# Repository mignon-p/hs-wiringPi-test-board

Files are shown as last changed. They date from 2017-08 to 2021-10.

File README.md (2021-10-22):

This is a simple add-on board for [Raspberry Pi][1].  It is meant for
testing the [Haskell binding for wiringPi][2].  It connects to the
Raspberry Pi via a 40-pin ribbon cable, and has the following
features:

* [wiringPi pins][3] 0-7 are connected to yellow LEDs

* wiringPi pins 26 and 23 are connected to red LEDs

* wiringPi pins 21 and 22 are connected to each other (via a resistor
  to prevent short circuits) to allow for automated testing (i. e. an
  output pin sending to an input pin)

* wiringPi pin 25 is connected to a momentary pushbutton which pulls
  it to ground via a resistor (so pin should be configured with an
  internal pullup)

The LEDs are driven [with transistors][4] from the 5V supply, to avoid
overloading the 3.3V supply.

This circuit board was designed with [KiCad][5], and was designed to
be fabricated with [OSH Park][6].

* [View schematic](schematic.pdf)
* [View PCB layout][9]
* [Order PCB from Osh Park][10] ($27.40 for three copies of the board,
  and free shipping)

See `digi-key.csv` for Bill of Materials with [Digi-Key][7] part
numbers.  With the 33 ohm resistors, the LEDs are really bright, so
you might want to substitute 68 ohm resistors instead.

This repository is licensed under the
[Creative Commons Attribution-ShareAlike 4.0 International license][8].

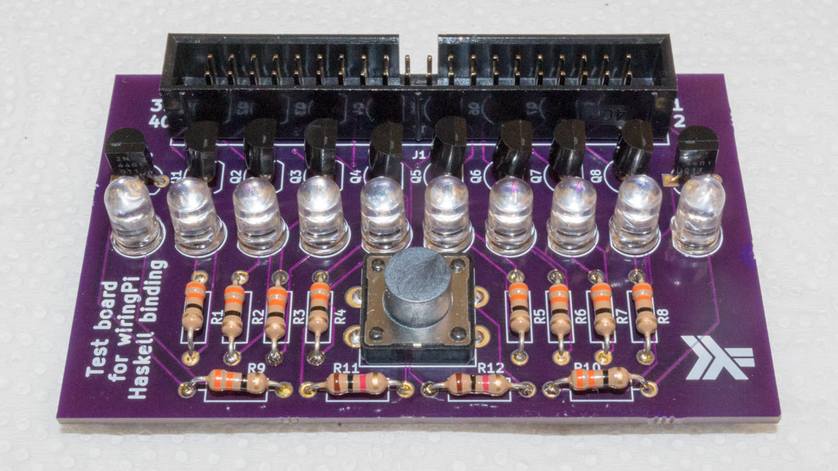
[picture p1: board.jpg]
photo of board


[1]: https://www.raspberrypi.org/
[2]: https://hackage.haskell.org/package/wiringPi
[3]: https://pinout.xyz/pinout/wiringpi
[4]: https://electronics.stackexchange.com/questions/60865/how-to-drive-a-20ma-led-from-a-4ma-max-gpio-pin#60868
[5]: http://kicad.org/
[6]: https://oshpark.com/
[7]: https://www.digikey.com/
[8]: https://creativecommons.org/licenses/by-sa/4.0/
[9]: https://eyrie.io/board/922367d680304403abe881f246e2a430
[10]: https://oshpark.com/shared_projects/bw71UDHZ

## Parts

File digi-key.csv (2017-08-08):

# | Quantity | Part Number | Manufacturer Part Number | Description | Customer Reference | Backorder | Unit Price | Extended Price
1 | 10 | 2N4401-APCT-ND | 2N4401-AP | TRANS NPN 40V TO92 | Q1-Q10 | 0 | 0.17800 | 1.78
2 | 10 | CF14JT33R0CT-ND | CF14JT33R0 | RES 33 OHM 1/4W 5% AXIAL | R1-R10 | 0 | 0.04000 | 0.40
3 | 8 | C503B-ACN-CX0Y0251-ND | C503B-ACN-CX0Y0251 | LED AMBER CLEAR 5MM ROUND T/H | D1-D8 | 0 | 0.16000 | 1.28
4 | 2 | C503B-RCN-CW0Z0AA1-ND | C503B-RCN-CW0Z0AA1 | LED RED CLEAR 5MM ROUND T/H | D9-D10 | 0 | 0.15000 | 0.30
5 | 2 | CF14JT1K00CT-ND | CF14JT1K00 | RES 1K OHM 1/4W 5% AXIAL | R11-R12 | 0 | 0.10000 | 0.20
6 | 1 | 430476085716-ND | 430476085716 | SWITCH TACTILE SPST-NO 0.05A 12V | SW1 | 0 | 0.49000 | 0.49
7 | 1 | S9175-ND | SBH11-PBPC-D20-ST-BK | CONN HEADER 2.54MM 40POS GOLD | J1 | 0 | 0.91000 | 0.91
8 | 4 | 36-780-B-ND | 780-B | BUMPER CYLIN 0.375" DIA BLACK |  | 0 | 0.16000 | 0.64
9 | 1 | H3CCS-4006G-ND | H3CCS-4006G | IDC CBL - HHKC40S/AE40G/HHKC40S |  | 1 | 1.66000 | 1.66

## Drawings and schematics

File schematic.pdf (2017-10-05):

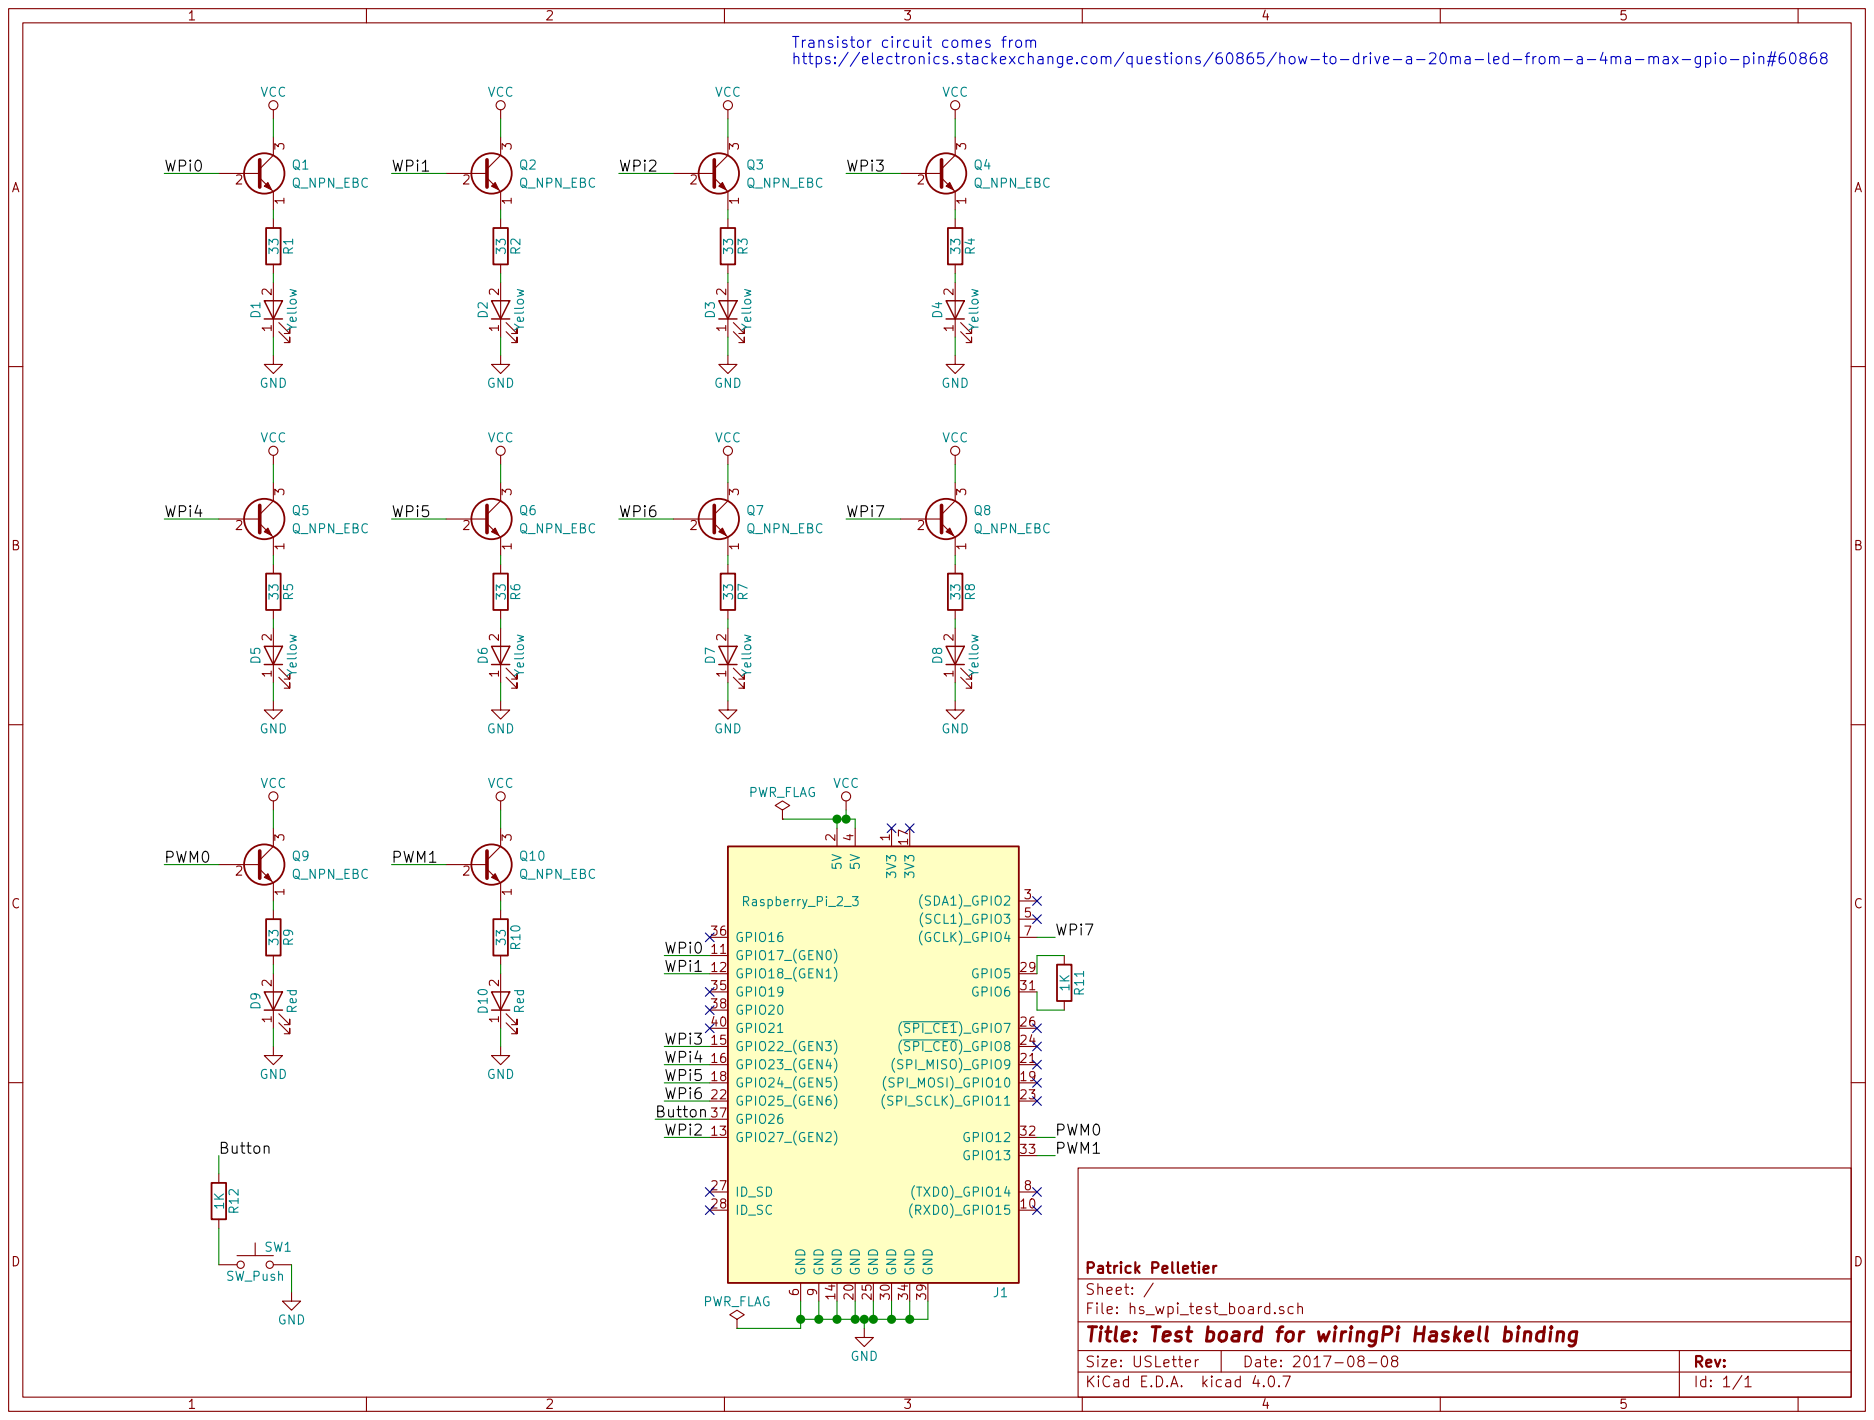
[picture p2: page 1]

Transistor circuit comes from
https://electronics.stackexchange.com/questions/60865/how-to-drive-a-20ma-led-from-a-4ma-max-gpio-pin#60868
VCC33R3

File: hs_wpi_test_board.sch Sheet: / Patrick Pelletier 3V3

Id: 1/1 Title: Test board for wiringPi Haskell binding

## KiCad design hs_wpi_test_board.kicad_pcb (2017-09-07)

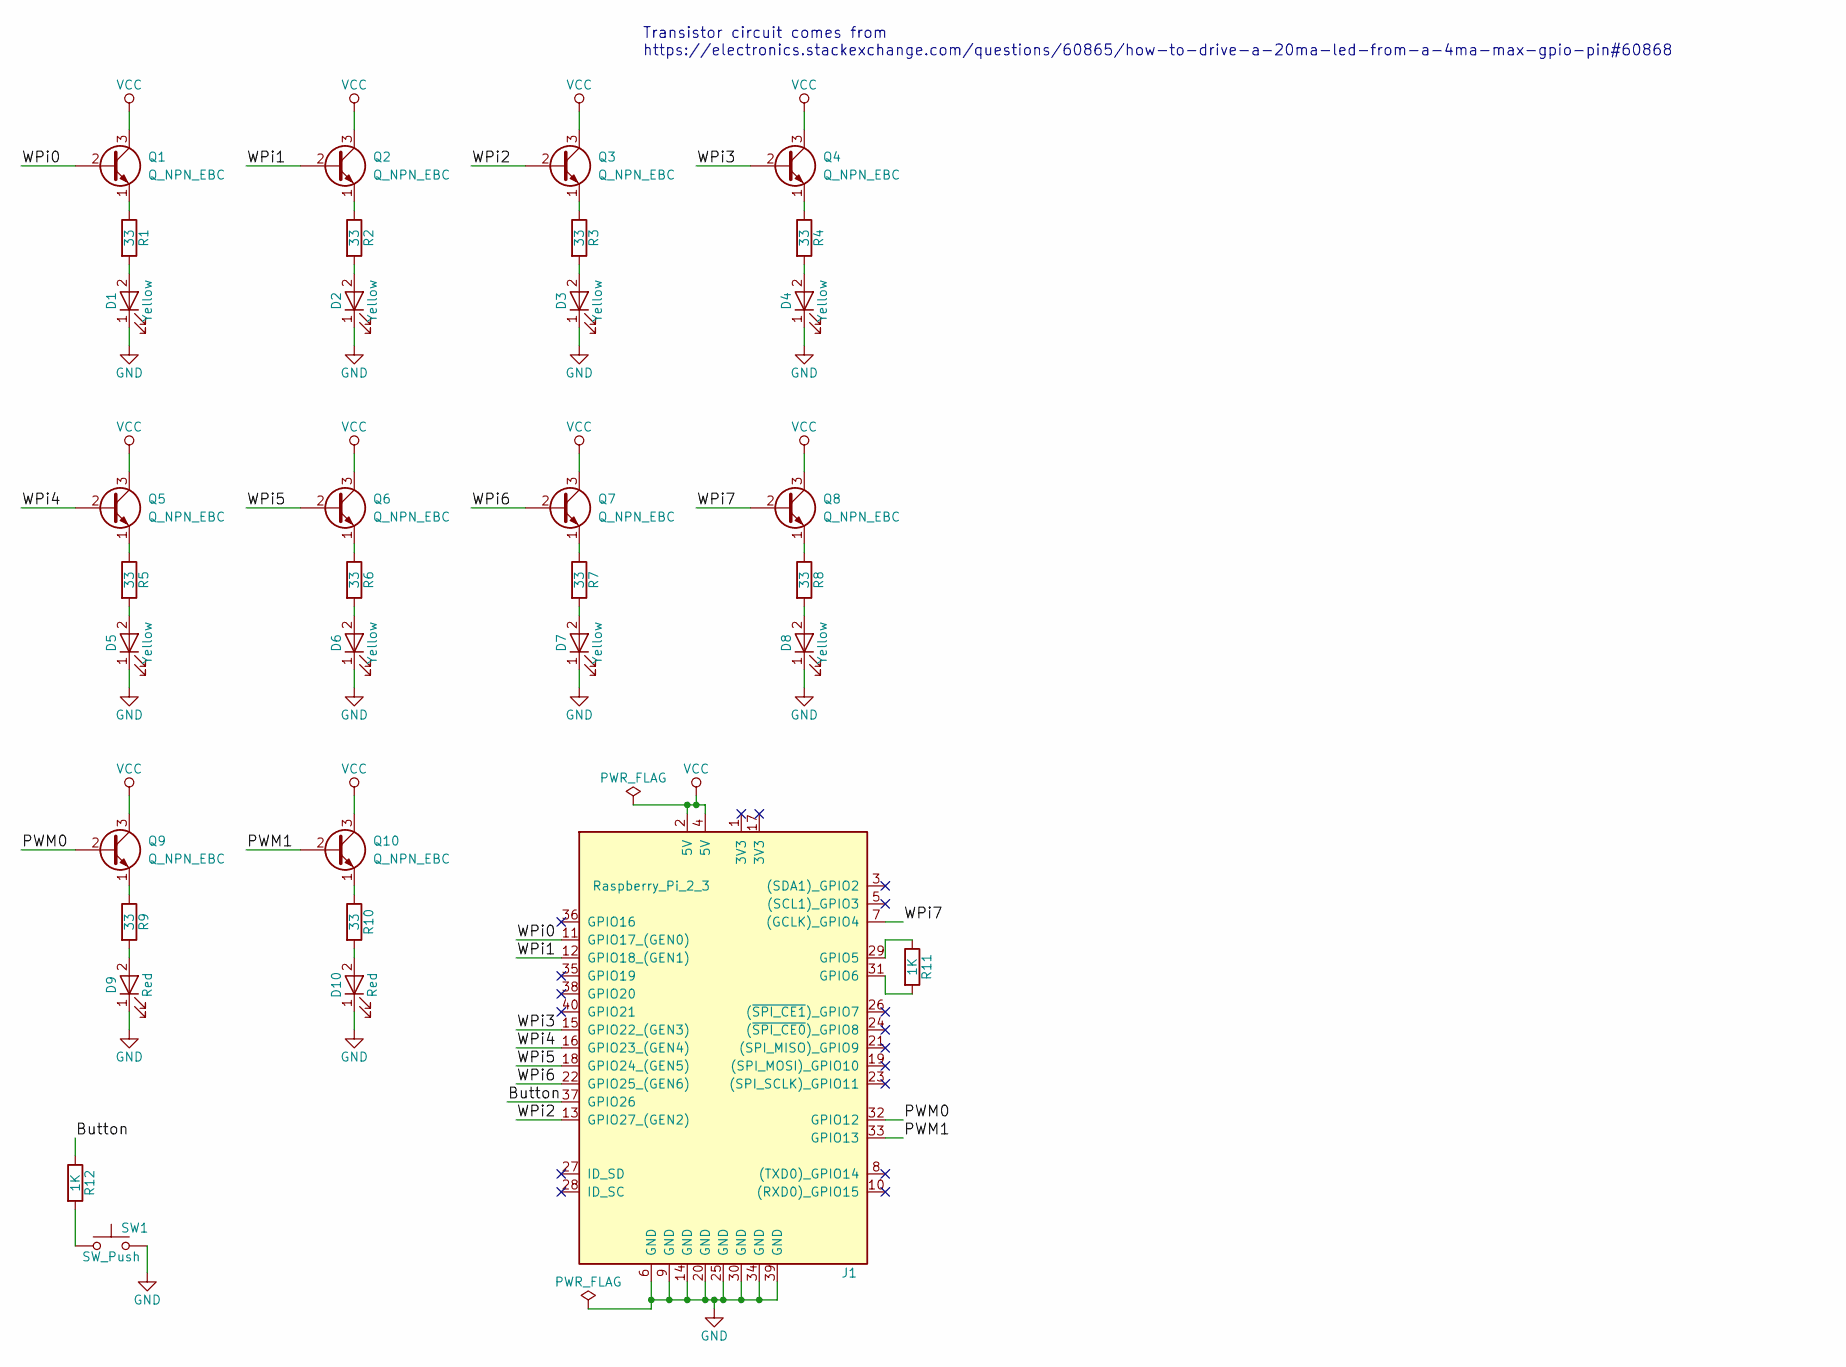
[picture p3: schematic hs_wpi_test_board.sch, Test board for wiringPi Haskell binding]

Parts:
D1, D2, D3, D4, D5, D6, D7, D8: Yellow; LED_D5.0mm
D9, D10: Red; LED_D5.0mm
J1: Raspberry_Pi_2_3; IDC_Header_Straight_40pins
Q1, Q2, Q3, Q4, Q5, Q6, Q7, Q8, Q9, Q10: Q_NPN_EBC; TO-92_Inline_Wide
R1, R2, R3, R4, R5, R6, R7, R8, R9, R10: 33; R_Axial_DIN0207_L6.3mm_D2.5mm_P10.16mm_Horizontal
R11, R12: 1K; R_Axial_DIN0207_L6.3mm_D2.5mm_P10.16mm_Horizontal
SW1: SW_Push; SW_PUSH-12mm_Wurth-430476085716

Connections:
/Button: J1.37 (GPIO26), R12.1
/PWM0: J1.32 (GPIO12), Q9.2 (B)
/PWM1: J1.33 (GPIO13), Q10.2 (B)
/WPi0: J1.11 (GPIO17_(GEN0)), Q1.2 (B)
/WPi1: J1.12 (GPIO18_(GEN1)), Q2.2 (B)
/WPi2: J1.13 (GPIO27_(GEN2)), Q3.2 (B)
/WPi3: J1.15 (GPIO22_(GEN3)), Q4.2 (B)
/WPi4: J1.16 (GPIO23_(GEN4)), Q5.2 (B)
/WPi5: J1.18 (GPIO24_(GEN5)), Q6.2 (B)
/WPi6: J1.22 (GPIO25_(GEN6)), Q7.2 (B)
/WPi7: J1.7 ((GCLK)_GPIO4), Q8.2 (B)
GND: D1.1 (K), D2.1 (K), D3.1 (K), D4.1 (K), D5.1 (K), D6.1 (K), D7.1 (K), D8.1 (K), D9.1 (K), D10.1 (K), J1.6 (GND), J1.9 (GND), J1.14 (GND), J1.20 (GND), J1.25 (GND), J1.30 (GND), J1.34 (GND), J1.39 (GND), SW1.2
unnamed: D1.2 (A), R1.2
unnamed: D2.2 (A), R2.2
unnamed: D3.2 (A), R3.2
unnamed: D4.2 (A), R4.2
unnamed: D5.2 (A), R5.2
unnamed: D6.2 (A), R6.2
unnamed: D7.2 (A), R7.2
unnamed: D8.2 (A), R8.2
unnamed: D9.2 (A), R9.2
unnamed: D10.2 (A), R10.2
unnamed: J1.29 (GPIO5), R11.1
unnamed: J1.31 (GPIO6), R11.2
unnamed: Q1.1 (E), R1.1
unnamed: Q2.1 (E), R2.1
unnamed: Q3.1 (E), R3.1
unnamed: Q4.1 (E), R4.1
unnamed: Q5.1 (E), R5.1
unnamed: Q6.1 (E), R6.1
unnamed: Q7.1 (E), R7.1
unnamed: Q8.1 (E), R8.1
unnamed: Q9.1 (E), R9.1
unnamed: Q10.1 (E), R10.1
unnamed: R12.2, SW1.1
VCC: J1.2 (5V), J1.4 (5V), Q1.3 (C), Q2.3 (C), Q3.3 (C), Q4.3 (C), Q5.3 (C), Q6.3 (C), Q7.3 (C), Q8.3 (C), Q9.3 (C), Q10.3 (C)

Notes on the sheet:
Transistor circuit comes from https://electronics.stackexchange.com/questions/60865/how-to-drive-a-20ma-led-from-a-4ma-max-gpio-pin#60868

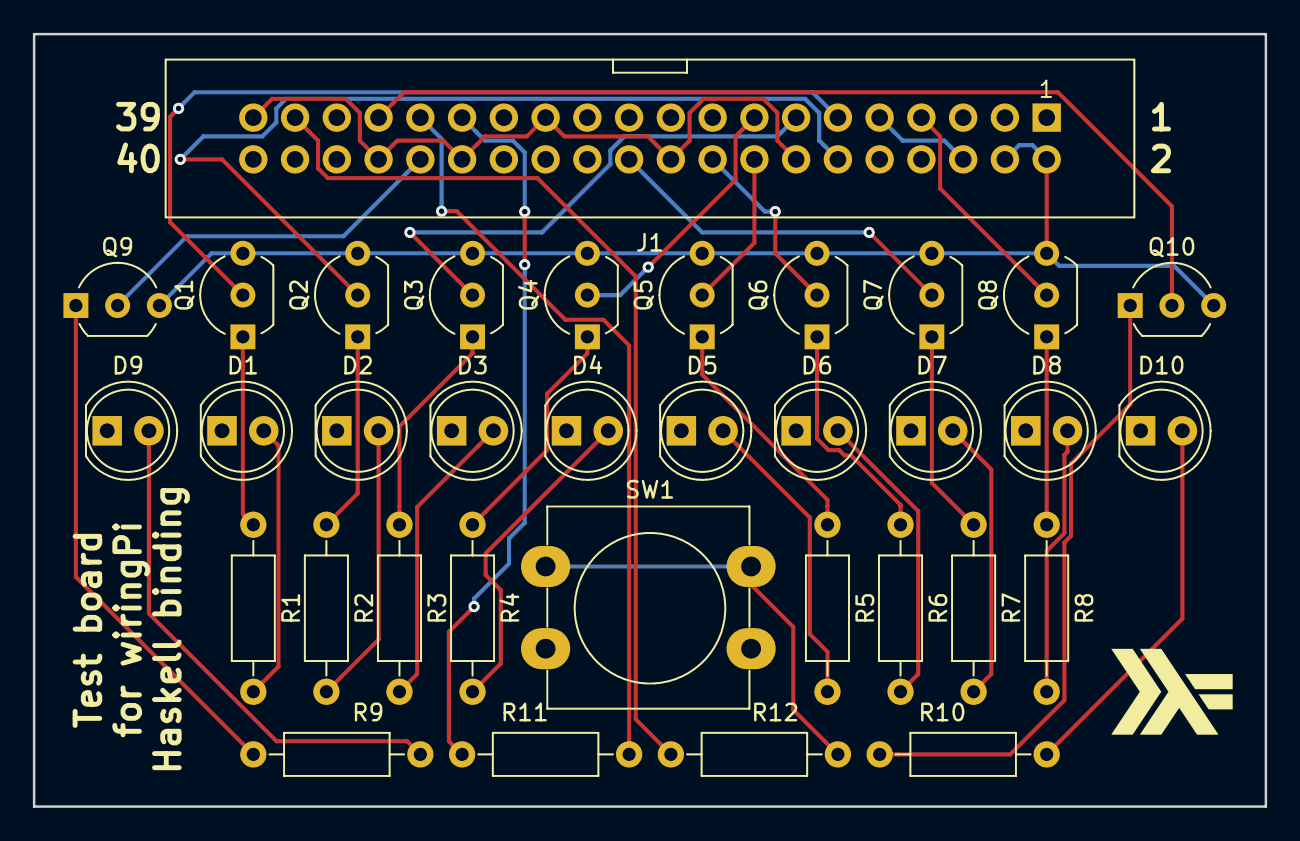
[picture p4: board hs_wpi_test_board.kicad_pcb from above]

Board: 2 copper layers, 74.9 x 47.0 mm, 34 parts (0 on the bottom side), 36 nets.

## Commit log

2017-08-07 add power flags and no connects
    [hs_wpi_test_board.sch]
2017-08-07 associate footprints
    [hs_wpi_test_board.sch]
2017-08-07 imported netlist
    [hs_wpi_test_board.kicad_pcb]
2017-08-07 change footprint for J1
    [hs_wpi_test_board.sch]
2017-08-07 angled socket
    [hs_wpi_test_board.kicad_pcb, hs_wpi_test_board.sch]
2017-08-07 pin header straight
    [hs_wpi_test_board.kicad_pcb, hs_wpi_test_board.sch]
2017-08-07 place components
    [hs_wpi_test_board.kicad_pcb]
2017-08-07 add board outline
    [hs_wpi_test_board.kicad_pcb]
2017-08-07 routed some stuff
    [hs_wpi_test_board.kicad_pcb]
2017-08-07 finished board
    [hs_wpi_test_board.kicad_pcb]
2017-08-07 switch J1 footprint to Connectors:IDC_Header_Straight_40pins
    [hs_wpi_test_board.kicad_pcb, hs_wpi_test_board.sch]
2017-08-08 add feet on silkscreen
    [hs_wpi_test_board.kicad_pcb]
2017-08-08 remove all routing
    [hs_wpi_test_board.kicad_pcb]
2017-08-08 switch to wider footprint for transistors
    [hs_wpi_test_board.kicad_pcb, hs_wpi_test_board.sch]
2017-08-08 work in progress
    [hs_wpi_test_board.kicad_pcb]
2017-08-08 position footprints
    [hs_wpi_test_board.kicad_pcb]
2017-08-08 draw board outline
    [hs_wpi_test_board.kicad_pcb]
2017-08-08 finish routing
    [hs_wpi_test_board.kicad_pcb]
2017-08-08 silkscreen text
    [hs_wpi_test_board.kicad_pcb]
2017-08-08 not sure where that came from
    [hs_wpi_test_board.kicad_pcb]
2017-08-08 add Haskell logo footprint
2017-08-08 add Haskell logo to board
    [hs_wpi_test_board.kicad_pcb]
2017-08-08 move some vias around to avoid silkscreen
    [hs_wpi_test_board.kicad_pcb]
2017-08-08 adjust resistor silkscreen locations
    [hs_wpi_test_board.kicad_pcb]
2017-08-08 update Haskell logo footprint with pretty-printing and timestamp
2017-08-08 add some text to schematic
    [hs_wpi_test_board.sch]
2017-08-08 add documentation
    [digi-key.csv]
2017-08-08 update text on silkscreen
    [hs_wpi_test_board.kicad_pcb]
2017-08-08 add KiCad and OSHW logos to back silkscreen
    [hs_wpi_test_board.kicad_pcb]
2017-08-08 more drawings on silkscreen to indicate position of J1
    [hs_wpi_test_board.kicad_pcb]
2017-08-23 push button footprint with bigger holes
2017-08-23 use new button footprint
    [hs_wpi_test_board.kicad_pcb, hs_wpi_test_board.sch]
2017-08-23 make board a little larger
    [hs_wpi_test_board.kicad_pcb]
2017-08-23 Like IDC_Header_Straight_40pins from library, but with notch on silkscreen.
    This makes it clearer which way the connector should go.
2017-08-23 use connector footprint with notch on silkscreen
    [hs_wpi_test_board.kicad_pcb, hs_wpi_test_board.sch]
2017-08-23 allow better connections to ground plane from more pins
    [hs_wpi_test_board.kicad_pcb]
2017-09-07 change soldermask clearance to 2 mils
    I was getting shorts, and OSH Park said:
    "Oh, the easy fix here is to reduce your mask expansion. We recommend
    2 mil. When the mask expansion is larger than this, it can sometimes
    wind up exposing nearby traces. It's sadly a problem that design tools
    don't really warn you about, and a lot of folks simply have to
    discover this on their own."
    [hs_wpi_test_board.kicad_pcb]
2017-09-07 add photo of board
2017-09-07 update date and revision
    [hs_wpi_test_board.kicad_pcb]
2017-10-05 Add schematic PDF, and links to Eyrie and OSH Park.
2021-10-22 Link to kicad.org
    https://forum.kicad.info/t/warning-avoid-all-links-to-kicad-pcb-org-use-kicad-org/31521
